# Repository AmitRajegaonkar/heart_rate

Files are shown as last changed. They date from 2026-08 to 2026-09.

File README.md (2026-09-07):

# ESP32 + MAX30102 — Clinical Pulse Monitor
## Complete Setup Guide: PlatformIO → Upload → Python Dashboard

---

## 📁 Project Structure

```
heart/
├── pulse_monitor.py        ← Python desktop GUI (run this to view live data)
├── requirements.txt        ← Python dependencies
├── README.md               ← This file
└── heart/                   ← PlatformIO ESP32 firmware project
    ├── platformio.ini      ← Board & library config
    └── src/
        └── main.cpp        ← ESP32 firmware (reads MAX30102, sends over USB)
```

---

## 🔌 Hardware Wiring

| MAX30102 Pin | ESP32 Pin |
|---|---|
| VIN | 3.3V |
| GND | GND |
| SDA | GPIO 21 |
| SCL | GPIO 22 |

> ⚠️ **Do NOT connect SDA to D2 (GPIO2) or D15 (GPIO15)** — these are ESP32 strapping pins and will block flashing.

Keep wire length **under 30 cm** between sensor and ESP32.

---

## ⚙️ Part 1 — ESP32 Firmware Setup (PlatformIO)

### Step 1 — Install VS Code + PlatformIO

1. Download and install [VS Code](https://code.visualstudio.com/)
2. Open VS Code → Extensions (Ctrl+Shift+X) → Search **PlatformIO IDE** → Install
3. Restart VS Code

### Step 2 — Open the Firmware Project

1. In VS Code, click the **PlatformIO Home** icon (ant icon in sidebar)
2. Click **Open Project**
3. Browse to `c:\Users\amitr\Desktop\heart\heart` → Click **Open**

### Step 3 — Install the Library

PlatformIO will automatically install the **SparkFun MAX3010x** library listed in `platformio.ini` on first build. No manual steps needed.

### Step 3b — Configure Wi-Fi Credentials (Optional for Wireless Mode)

If you plan to stream live data wirelessly over Wi-Fi:
1. Open [`heart/src/main.cpp`](file:///c:/Users/amitr/Desktop/heart/heart/src/main.cpp)
2. Locate lines 20–21:
   ```cpp
   // ── Wi-Fi credentials ──────────────────────────────────────────────────────
   const char* WIFI_SSID = "YOUR_WIFI_SSID";
   const char* WIFI_PASS = "YOUR_WIFI_PASSWORD";
   ```
3. Replace `"YOUR_WIFI_SSID"` and `"YOUR_WIFI_PASSWORD"` with your 2.4 GHz Wi-Fi router or mobile hotspot details.
4. Save the file (`Ctrl+S`).

> ℹ️ *Note: ESP32 only connects to **2.4 GHz** Wi-Fi networks (not 5 GHz).*

### Step 4 — Build the Firmware

- Click the **✓ Build** button (bottom toolbar) or press `Ctrl+Alt+B`
- Wait for: `[SUCCESS]`

### Step 5 — Upload to ESP32

1. Plug in your ESP32 via USB
2. Click the **→ Upload** button (bottom toolbar) or press `Ctrl+Alt+U`
3. If upload fails with "Wrong boot mode":
   - **Hold the BOOT button** on the ESP32 while clicking Upload
   - Release after "Connecting..." appears

### Step 6 — Verify with Serial Monitor

- Click the **🔌 Serial Monitor** icon in PlatformIO
- Set baud rate to **115200**
- You should see:
  ```text
  === ESP32 Pulse Monitor (Text Mode) ===
  Connecting to Wi-Fi.....
  Wi-Fi connected! IP: 192.168.1.150
  >>> Python Wi-Fi URL: http://192.168.1.150/events <<<
  Heart Rate: 72 BPM | SpO2: 98 % | Wave: 12.3 | IR DC: 45231
  ```
- ✅ Note the **IP address** printed (e.g. `192.168.1.150`) if you wish to use Wi-Fi mode.
- ❌ **Important:** Close the PlatformIO Serial Monitor before opening the Python app when using USB mode.

---

## 🐍 Part 2 — Python Dashboard Setup

### Step 1 — Install Python

Download Python 3.10+ from https://www.python.org/downloads/

> During install: check **"Add Python to PATH"**

Verify in PowerShell:
```powershell
python --version
```

### Step 2 — Create Virtual Environment

Open **PowerShell** and run:

```powershell
cd c:\Users\amitr\Desktop\heart

# Create virtual environment
python -m venv venv

# Activate it (Windows PowerShell)
.\venv\Scripts\Activate.ps1
```

> If you get a "scripts disabled" error, run this first:
> ```powershell
> Set-ExecutionPolicy -ExecutionPolicy RemoteSigned -Scope CurrentUser
> ```
> Then re-run `.\venv\Scripts\Activate.ps1`

Your prompt should now show `(venv)`:
```
(venv) PS C:\Users\amitr\Desktop\heart>
```

### Step 3 — Install Dependencies

With the virtual environment active:

```powershell
pip install -r requirements.txt
```

Expected output:
```
Successfully installed pyserial-3.5 matplotlib-3.9.2 requests-2.32.3
```

### Step 4 — Run the Dashboard

```powershell
python pulse_monitor.py
```

---

## 🖥️ Using the Dashboard

You can use the dashboard in either **USB Serial Mode** or **Wireless Wi-Fi Mode**:

### Mode A: USB Serial Mode (Default)
1. Select the **USB Serial** radio button.
2. Choose your **COM Port** from the dropdown (e.g. `COM4` or `COM5`).
   - If not listed, click **↺** to refresh.
3. Click **Connect**.

### Mode B: Wireless Wi-Fi Mode
1. Select the **Wi-Fi** radio button at the top bar.
2. Enter the **ESP32 IP address** (e.g. `192.168.1.150` — shown in Serial Monitor during ESP32 boot).
3. Click **Connect** (connects directly to `http://<IP>/events` via SSE).

---

### Dashboard Readings & Features

| Reading | Normal Range | Notes |
|---|---|---|
| Heart Rate | 60–100 BPM | Calculated over recent detected beats |
| Blood Oxygen | 95–100 % | Hold still for steady reading |
| Pulse Signal | Active Pulse | Shows "No Contact" if sensor detached |
| PPG Waveform | Smooth peaks | Starts from the left ($x=0$) on white background |
| ⏺ Record | Text File Log | Records session with timestamps to `ppg_<timestamp>.txt` |

---

## 🔧 Troubleshooting

| Problem | Fix |
|---|---|
| `ERROR: MAX30102 not found!` | Check wiring — SDA→21, SCL→22, VIN→3.3V |
| Upload fails "Wrong boot mode" | Hold BOOT button during upload |
| COM port not in dropdown | Click **Refresh** in the Python app |
| `No module named serial` | Run `pip install -r requirements.txt` in active venv |
| BPM shows `--` | Press finger more firmly; wait 10 seconds |
| SpO2 shows `--` | Hold completely still; takes ~10 seconds |
| Python app + Serial Monitor both open | Close PlatformIO Serial Monitor first |

---

## 📡 Data Format (For Researchers)

The ESP32 sends formatted text over USB Serial (at 115200 baud) and Wi-Fi SSE (`/events`):

```text
Heart Rate: <bpm> BPM | SpO2: <spo2> % | Wave: <wave> | IR DC: <irDC>
```

| Field | Type | Description |
|---|---|---|
| `Heart Rate` | int / text | Average heart rate over recent detected beats (`--` if detecting) |
| `SpO2` | int / text | Blood oxygen % calculated from Red/IR AC/DC ratio |
| `Wave` | float | Filtered pulsatile PPG AC signal (centered at 0) |
| `IR DC` | long | IR baseline amplitude (finger/carotid contact quality) |

To log raw data to a text file using Python:
```python
import serial, time
ser = serial.Serial('COM5', 115200)
with open('ppg_log.txt', 'w', encoding='utf-8') as f:
    while True:
        line = ser.readline().decode('utf-8', errors='ignore').strip()
        if line:
            f.write(f"[{time.strftime('%Y-%m-%d %H:%M:%S')}] {line}\n")
            f.flush()
```

---

## 🔬 For PhD Research Use

- The PPG waveform (`wave`) is the primary signal for analysis
- `irDC > 50000` confirms solid sensor contact
- For neck placement: increase LED brightness in `main.cpp`:
  ```cpp
  particleSensor.setup(0x3F, 8, 2, 200, 411, 4096);
  ```
- Validate BPM against a medical reference (Polar H10, ECG) using Bland-Altman analysis
- Raw waveform can be post-processed with Pan-Tompkins or Elgendi algorithm for research-grade peak detection

---

## 📋 Quick Reference

```powershell
# Every time you want to run the dashboard:
cd c:\Users\amitr\Desktop\heart
.\venv\Scripts\Activate.ps1
python pulse_monitor.py
```

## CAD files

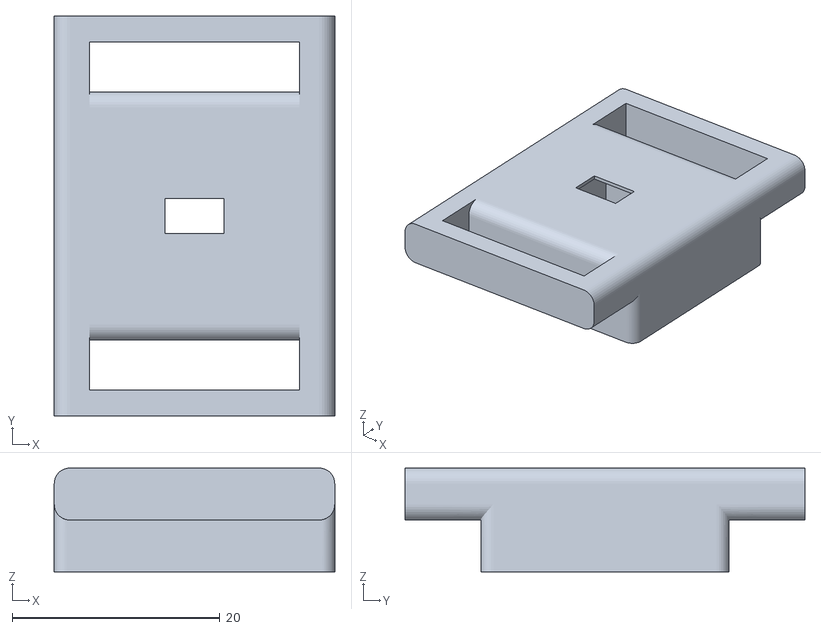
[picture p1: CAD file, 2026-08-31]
3dprinted_file/Body3.stl
27.0 x 38.5 x 10.0

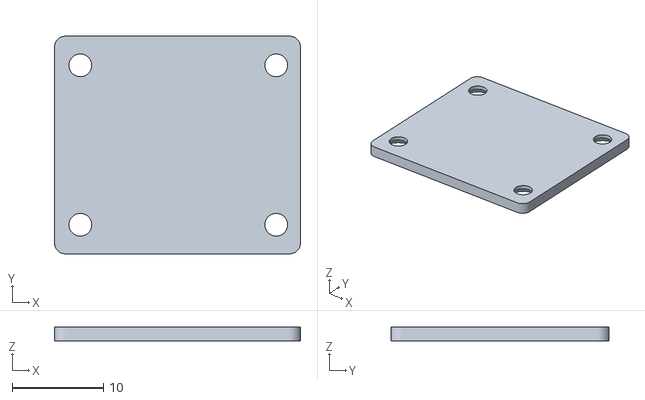
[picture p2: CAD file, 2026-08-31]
3dprinted_file/top.stl
27.0 x 23.9 x 1.50

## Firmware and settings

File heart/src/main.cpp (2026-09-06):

/*
 * ESP32 + MAX30102 — Dual Mode: USB Serial + Wi-Fi SSE (Text Output Mode)
 * ------------------------------------------------------------------------
 * Streams human-readable text over USB Serial
 * AND serves live text stream via Wi-Fi SSE at http://<IP>/events
 *
 * Wiring:
 *   VIN  → 3.3 V   SDA → GPIO 21   SCL → GPIO 22   GND → GND
 */

#include <Arduino.h>
#include <Wire.h>
#include <WiFi.h>
#include <WebServer.h>
#include "MAX30105.h"
#include "heartRate.h"

// ── Wi-Fi credentials ──────────────────────────────────────────────────────
const char* WIFI_SSID = "7ii_2";
const char* WIFI_PASS = "16988444";

// ── I2C pins ───────────────────────────────────────────────────────────────
#define SDA_PIN 21
#define SCL_PIN 22

// ── Neck sensing thresholds ────────────────────────────────────────────────
#define CONTACT_THRESHOLD 12000
#define RESET_THRESHOLD    4000

// ── Globals ────────────────────────────────────────────────────────────────
MAX30105  particleSensor;
WebServer server(80);
WiFiClient sseClient;
bool       sseActive = false;

// ── Medical PPG DSP Filters (High-Pass DC Blocker + 2-Stage Low-Pass) ──────
struct PPGFilter {
  float dcAlpha; // DC blocker coefficient (~0.94 for ~0.4 Hz high-pass at 25Hz)
  float lpAlpha; // Low-pass coefficient (~0.45 for ~4.0 Hz low-pass at 25Hz)
  float w;
  float lp1;
  float lp2;

  void init(float highPassCutoffAlpha = 0.94f, float lowPassAlpha = 0.45f) {
    dcAlpha = highPassCutoffAlpha;
    lpAlpha = lowPassAlpha;
    reset();
  }

  float process(float x) {
    // 1. DC-Removal (High-Pass Filter removes slow breathing baseline wander)
    float curr_w = x + dcAlpha * w;
    float hp = curr_w - w;
    w = curr_w;

    // 2. Cascaded 2-Stage Low-Pass (Removes muscle tremors & 50/60Hz noise)
    lp1 = lp1 * (1.0f - lpAlpha) + hp * lpAlpha;
    lp2 = lp2 * (1.0f - lpAlpha) + lp1 * lpAlpha;
    return lp2;
  }

  void reset() {
    w   = 0.0f;
    lp1 = 0.0f;
    lp2 = 0.0f;
  }
};

PPGFilter irFilter;
PPGFilter redFilter;

// Heart Rate
const byte RATE_SIZE = 6;
byte  rates[RATE_SIZE];
byte  rateSpot = 0;
long  lastBeat = 0;
int   beatAvg  = 0;

// DC levels for SpO2 & contact tracking
double irDC  = 0, redDC = 0;
double filteredIR = 0, filteredRed = 0;

// SpO2
long  minRed = 999999, maxRed = 0;
long  minIR  = 999999, maxIR  = 0;
float spo2Val = 0;

// ── SSE Handlers ───────────────────────────────────────────────────────────
void handleEvents() {
  sseClient = server.client();
  sseClient.print(
    "HTTP/1.1 200 OK\r\n"
    "Content-Type: text/event-stream\r\n"
    "Cache-Control: no-cache\r\n"
    "Connection: keep-alive\r\n"
    "Access-Control-Allow-Origin: *\r\n"
    "\r\n"
  );
  sseActive = true;
}

void handleRoot() {
  server.send(200, "text/plain",
    "ESP32 MAX30102 Pulse Monitor\n"
    "Connect Python app to: http://" + WiFi.localIP().toString() + "/events\n"
    "Or use USB Serial at 115200 baud.\n"
  );
}

// ── Setup ──────────────────────────────────────────────────────────────────
void setup() {
  Serial.begin(115200);
  delay(400);
  Serial.println("\n=== Dual Mode: USB + Wi-Fi (Stabilized Baseline) ===");

  irFilter.init(0.94f, 0.45f);
  redFilter.init(0.94f, 0.45f);

  Wire.begin(SDA_PIN, SCL_PIN);
  Wire.setClock(100000);

  if (!particleSensor.begin(Wire, I2C_SPEED_STANDARD)) {
    Serial.println("ERROR: MAX30102 not found!");
    while (true) { delay(1000); }
  }

  // ── NECK / CAROTID optimised settings ─────────────────────────────────
  // 0x3F (~12mA) is correct for neck — thick tissue absorbs most IR light
  // so irDC stays in 15,000–50,000 range (well below ADC ceiling of 262143).
  // Sample average = 8  → smooths out neck muscle motion artefacts
  // Sample rate   = 200 Hz → effective FIFO rate = 25 Hz
  // Pulse width   = 411 us → maximum integration = best SNR for weak signal
  particleSensor.setup(0x3F, 8, 2, 200, 411, 4096);
  particleSensor.setPulseAmplitudeRed(0x3F);  // ~12 mA Red
  particleSensor.setPulseAmplitudeIR(0x3F);   // ~12 mA IR

  // Connect to Wi-Fi
  WiFi.mode(WIFI_STA);
  WiFi.begin(WIFI_SSID, WIFI_PASS);
  Serial.print("Connecting to Wi-Fi");
  int attempts = 0;
  while (WiFi.status() != WL_CONNECTED && attempts < 20) {
    delay(500); Serial.print("."); attempts++;
  }
  if (WiFi.status() == WL_CONNECTED) {
    Serial.println("\nWi-Fi connected! IP: " + WiFi.localIP().toString());
    Serial.println(">>> Python Wi-Fi URL: http://" + WiFi.localIP().toString() + "/events <<<");
  } else {
    Serial.println("\n!!! Wi-Fi FAILED — check SSID/password and 2.4GHz band !!!");
    Serial.println("USB Serial mode still active.");
  }

  server.on("/", HTTP_GET, handleRoot);
  server.on("/events", HTTP_GET, handleEvents);
  server.begin();

  Serial.println("USB Serial also active at 115200 baud.");
  Serial.println("Ready.");
}

// ── Loop ───────────────────────────────────────────────────────────────────
void loop() {
  server.handleClient();

  // Drain FIFO
  particleSensor.check();
  while (particleSensor.available()) {
    long irRaw  = particleSensor.getFIFOIR();
    long redRaw = particleSensor.getFIFORed();
    particleSensor.nextSample();

    if (irRaw > CONTACT_THRESHOLD) {
      // Slow exponential moving average for DC baseline (used for SpO2 & contact)
      // Slow time constant (~3s) so it does NOT follow or distort individual heart pulses
      irDC  = irDC  * 0.985 + (double)irRaw  * 0.015;
      redDC = redDC * 0.985 + (double)redRaw * 0.015;

      // Apply High-Pass (DC Blocker) + 2-Stage Low-Pass Filter
      filteredIR  = irFilter.process((float)irRaw);
      filteredRed = redFilter.process((float)redRaw);

      if (redRaw < minRed) minRed = redRaw;
      if (redRaw > maxRed) maxRed = redRaw;
      if (irRaw  < minIR)  minIR  = irRaw;
      if (irRaw  > maxIR)  maxIR  = irRaw;

      if (checkForBeat(irRaw)) {
        unsigned long now = millis();
        if (lastBeat != 0) {
          float bpm = 60000.0f / (float)(now - lastBeat);
          if (bpm >= 35.0f && bpm <= 200.0f) {
            rates[rateSpot++] = (byte)bpm;
            rateSpot %= RATE_SIZE;
            int sum = 0, count = 0;
            for (byte x = 0; x < RATE_SIZE; x++) {
              if (rates[x] > 0) { sum += rates[x]; count++; }
            }
            if (count > 0) beatAvg = sum / count;
          }
        }
        lastBeat = now;
      }

    } else {
      if (irRaw < RESET_THRESHOLD) {
        beatAvg = 0; lastBeat = 0; spo2Val = 0;
        irDC = 0; redDC = 0;
        filteredIR = 0; filteredRed = 0;
        irFilter.reset();
        redFilter.reset();
        for (byte i = 0; i < RATE_SIZE; i++) rates[i] = 0;
      }
    }
  }

  // SpO2 every 3s
  static unsigned long lastSpO2Time = 0;
  if (millis() - lastSpO2Time > 3000 && irDC > 0 && redDC > 0) {
    lastSpO2Time = millis();
    double redAC = maxRed - minRed;
    double irAC  = maxIR  - minIR;
    minRed = 999999; maxRed = 0;
    minIR  = 999999; maxIR  = 0;
    if (irAC > 50 && redAC > 20) {
      double R    = (redAC / redDC) / (irAC / irDC);
      double calc = 104.0 - 17.0 * R;
      if (calc >= 85.0 && calc <= 100.0) {
        spo2Val = (spo2Val < 1.0) ? calc : (spo2Val * 0.8 + calc * 0.2);
      }
    }
  }

  // Send data every 100ms in readable text format — both USB Serial and Wi-Fi SSE
  static unsigned long lastSend = 0;
  if (millis() - lastSend >= 100) {
    lastSend = millis();

    String bpmStr  = (beatAvg > 0) ? (String(beatAvg) + " BPM") : "--";
    String spo2Str = (spo2Val > 0) ? (String((int)spo2Val) + " %") : "--";
    String waveStr = String(filteredIR, 1);
    String irStr   = String((long)irDC);

    String payload;
    if (irDC >= CONTACT_THRESHOLD) {
      payload = "Heart Rate: " + bpmStr +
                " | SpO2: " + spo2Str +
                " | Wave: " + waveStr +
                " | IR DC: " + irStr;
    } else {
      payload = "Status: No Contact | Heart Rate: -- | SpO2: -- | IR DC: " + irStr;
    }

    // USB Serial
    Serial.println(payload);

    // Wi-Fi SSE
    if (sseActive && sseClient.connected()) {
      sseClient.print("data: " + payload + "\r\n\r\n");
    } else {
      sseActive = false;
    }
  }

  // Print IP every 10 seconds so you can always find it in Serial Monitor
  static unsigned long lastIPPrint = 0;
  if (millis() - lastIPPrint >= 10000) {
    lastIPPrint = millis();
    if (WiFi.status() == WL_CONNECTED) {
      Serial.println(">>> IP: " + WiFi.localIP().toString() + " | http://" + WiFi.localIP().toString() + "/events <<<");
    } else {
      Serial.println("!!! Wi-Fi disconnected — check router !!!");
    }
  }
}

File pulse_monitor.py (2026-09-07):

"""
Clinical Pulse Monitor - ESP32 + MAX30102
Supports two connection modes:
  1. USB Serial  — plug ESP32 into PC via USB cable
  2. Wi-Fi SSE   — connect over the same Wi-Fi network (no USB needed)

Requirements:
  pip install pyserial requests matplotlib
"""

import threading
import queue
import time
import csv
import os
import re
from datetime import datetime
import tkinter as tk
from tkinter import ttk, font as tkfont
import requests

import matplotlib
matplotlib.use("TkAgg")
import matplotlib.pyplot as plt
import matplotlib.animation as animation
from matplotlib.backends.backend_tkagg import FigureCanvasTkAgg

try:
    import serial
    import serial.tools.list_ports
    SERIAL_OK = True
except ImportError:
    SERIAL_OK = False

BAUD_RATE  = 115200
MAX_POINTS = 180
UPDATE_MS  = 30
Y_MIN      = -150
Y_MAX      = 150

C_BG    = "#0f172a"
C_CARD  = "#1e293b"
C_BORDER= "#334155"
C_RED   = "#f43f5e"
C_TEAL  = "#14b8a6"
C_BLUE  = "#38bdf8"
C_MUTED = "#64748b"
C_TEXT  = "#f1f5f9"
C_WAVE  = "#0284c7"
C_GREEN = "#10b981"


# ── USB Serial reader thread ───────────────────────────────────────────────
class SerialReader(threading.Thread):
    def __init__(self, port, q):
        super().__init__(daemon=True)
        self.port  = port
        self.q     = q
        self._stop = threading.Event()
        self.ser   = None

    def run(self):
        if not SERIAL_OK:
            self.q.put(("error", "pyserial not installed. Run: pip install pyserial"))
            return
        try:
            self.ser = serial.Serial(self.port, BAUD_RATE, timeout=1)
            time.sleep(0.5)
            self.ser.reset_input_buffer()
            while not self._stop.is_set():
                raw = self.ser.readline().decode("utf-8", errors="ignore").strip()
                if raw:
                    _parse_and_enqueue(raw, self.q)
        except Exception as e:
            self.q.put(("error", str(e)))

    def stop(self):
        self._stop.set()
        try:
            if self.ser and self.ser.is_open:
                self.ser.close()
        except Exception:
            pass


# ── Wi-Fi SSE reader thread ────────────────────────────────────────────────
class WiFiReader(threading.Thread):
    def __init__(self, ip, q):
        super().__init__(daemon=True)
        self.ip    = ip
        self.q     = q
        self._stop = threading.Event()

    def run(self):
        raw = self.ip.strip()
        if not raw.startswith("http://") and not raw.startswith("https://"):
            raw = "http://" + raw
        if not raw.endswith("/events"):
            raw = raw.rstrip("/") + "/events"
        url = raw

        try:
            with requests.get(url, stream=True, timeout=10) as resp:
                resp.raise_for_status()
                for line in resp.iter_lines(decode_unicode=True):
                    if self._stop.is_set():
                        break
                    if line:
                        if line.startswith("data:"):
                            _parse_and_enqueue(line[5:].strip(), self.q)
                        else:
                            _parse_and_enqueue(line.strip(), self.q)
        except requests.exceptions.ConnectionError:
            self.q.put(("error", f"Cannot reach {url} — check ESP32 IP & Wi-Fi"))
        except Exception as e:
            self.q.put(("error", str(e)))

    def stop(self):
        self._stop.set()


def _parse_and_enqueue(payload, q):
    # Support CSV format (e.g. DATA:12.3,75,98,45231 or 12.3,75,98,45231)
    clean = payload[5:].strip() if payload.startswith("DATA:") else payload.strip()
    if "," in clean and "Heart Rate" not in clean and "Wave" not in clean:
        parts = clean.split(",")
        if len(parts) == 4:
            try:
                wave  = float(parts[0])
                bpm   = int(parts[1])
                spo2  = int(parts[2])
                ir_dc = float(parts[3])
                q.put(("data", wave, bpm, spo2, ir_dc))
                return
            except ValueError:
                pass

    # Support human-readable text format
    # Example: "Heart Rate: 75 BPM | SpO2: 98 % | Wave: 12.3 | IR DC: 45231"
    # Example: "Status: No Contact | Heart Rate: -- | SpO2: -- | IR DC: 1420"
    try:
        wave = 0.0
        bpm = 0
        spo2 = 0
        ir_dc = 0.0
        matched = False

        m_wave = re.search(r"Wave:\s*([-\d\.]+)", payload)
        if m_wave:
            wave = float(m_wave.group(1))
            matched = True

        m_bpm = re.search(r"Heart Rate:\s*(\d+)", payload)
        if m_bpm:
            bpm = int(m_bpm.group(1))
            matched = True

        m_spo2 = re.search(r"SpO2:\s*(\d+)", payload)
        if m_spo2:
            spo2 = int(m_spo2.group(1))
            matched = True

        m_ir = re.search(r"IR DC:\s*(\d+)", payload)
        if m_ir:
            ir_dc = float(m_ir.group(1))
            matched = True

        if matched:
            q.put(("data", wave, bpm, spo2, ir_dc))
    except Exception:
        pass
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

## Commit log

2026-08-31 feat: initialize ESP32 project with SparkFun MAX3010x sensor library and initial 3D model support
    [Body3.stl, top.stl]
2026-09-07 feat: add Wi-Fi streaming support via SSE and update documentation for wireless connectivity.
